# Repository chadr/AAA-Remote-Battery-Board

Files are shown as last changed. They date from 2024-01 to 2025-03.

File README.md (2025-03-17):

# AAA Remote Battery Board - Updated!
 Remote RTC/CMOS/NVRAM battery for retro computer motherboards. Provides about +4.5V. Which is what most vintage motherboards require. +3V, like from a CR2032, is not appropriate!

 **Features:**
 * Higher voltage than CR2032 and higher capacity for longer life
 * Diode to prevent reverse charging
 * Diode delete solder jumper - NEW
 * Universal fuse holder footprint accepts wide and narrow spacing - NEW
 * 100ma fuse to protect motherboard if a short develops
 * Nylon fuse holder contains fuse blast and glass
 * Uses 1x4 pin headers found on most motherboards for simple cabling
 * PCB cutouts for Cable tie to secure batteries in rough service situations
 * Backer board to raise battery off case when using tape/velcro - NEW
 * Mounting holes for M3 standoffs
 * No motherboard modifications required!

<picture>
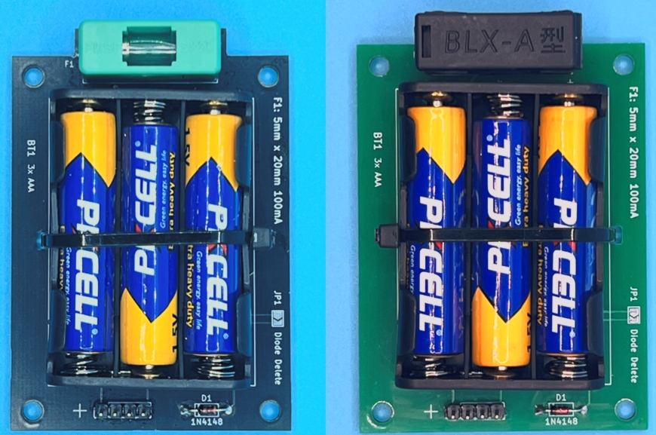
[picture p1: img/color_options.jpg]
AAA Battery Board Assembled
 
</picture>

<picture>
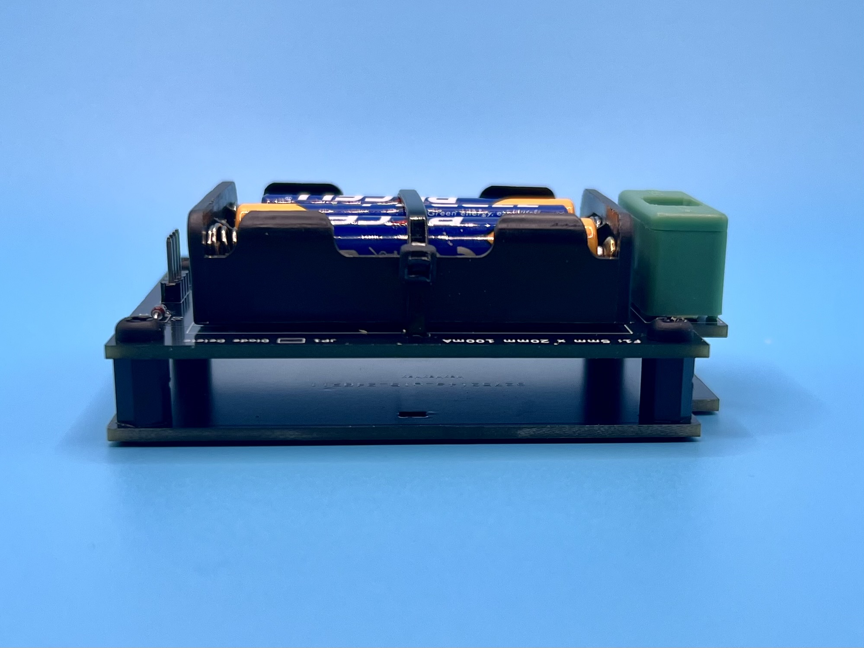
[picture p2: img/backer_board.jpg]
AAA Backer Board
  
</picture>

<picture>
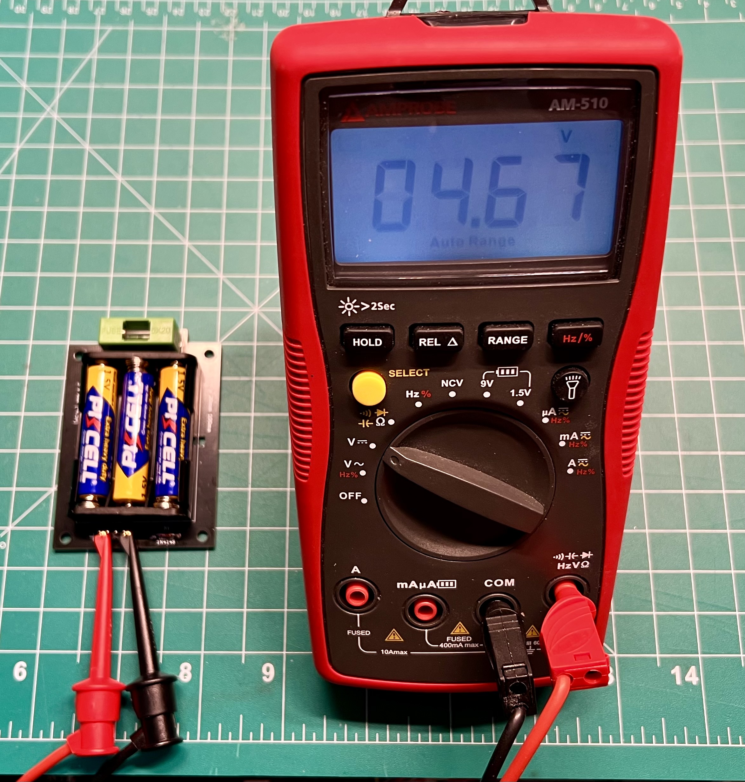
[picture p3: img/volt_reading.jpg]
AAA Battery Board Open Circuit Voltage
 
</picture>

## Here's a scan from a 386sx AT motherboard. Notice the voltages it requires. It warns against using +3V batteries like a CR2032!
<picture>
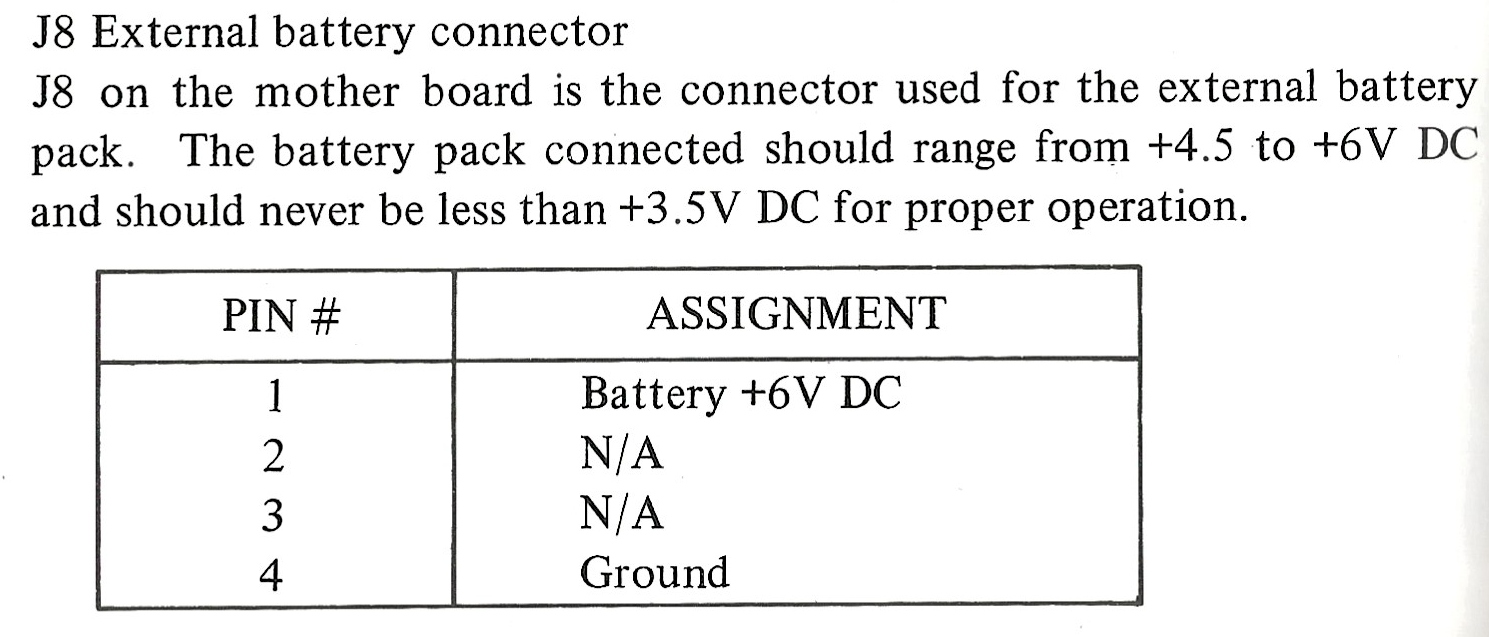
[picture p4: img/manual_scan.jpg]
Manual Scan
  
</picture>

## Bill of Materials
**Item**|**Qty**|**MFG Part Num**|**Mouser Part Num**
:-----:|:-----:|:-----:|:-----:
Keystone 3xAAA Holder|1|2479|534-2479
1N4148 Diode|1|1N4148-T50R|512-1N4148T50R
1x4 2.54mm Male Header|1|826926-4|571-826926-4
Fuse|1|BK1/GMC-100-R|504-BK1-GMC-100-R
Fuse Holder|1|0PTF0078P|576-0PTF0078P
Fuse Clip|1|00BS0232P|576-00BS0232P

## Board Information
Dimensions:  
Layers: 2  
Finish: HASL  
Make sure to choose "custom position" for order number /w JLCPCB or PCBWAY.  

## Purchasing
I sell assembled kits complete with cables, mounting hardware, and batteries in my [eBay store](https://www.ebay.com/str/pcrestoration).  
And on Tindie (Cheaper on Tindie due to lower fees!) [Link](https://www.tindie.com/products/33599/)



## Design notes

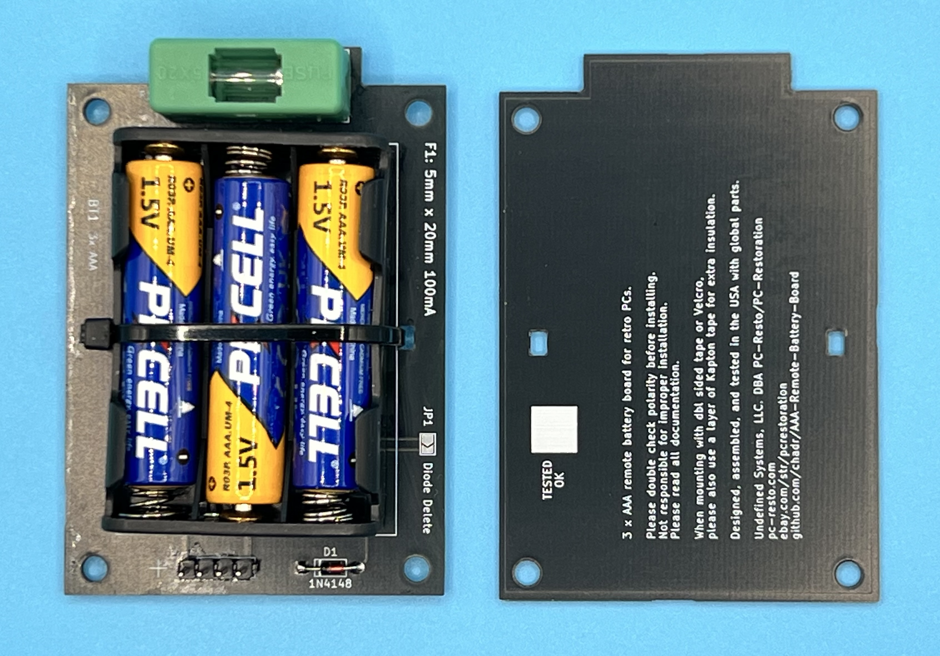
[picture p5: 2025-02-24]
img/with_backer.jpg

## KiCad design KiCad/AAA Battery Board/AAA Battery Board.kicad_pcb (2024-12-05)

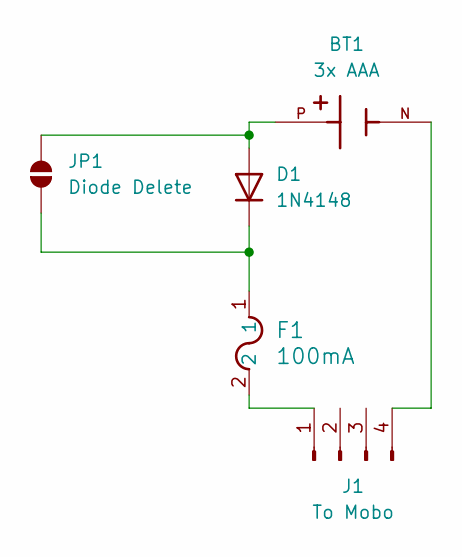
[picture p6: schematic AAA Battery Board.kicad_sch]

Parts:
BT1: 3x AAA; BAT_2479; PARTREV E
D1: 1N4148; D_DO-35_SOD27_P7.62mm_Horizontal
F1: 100mA; UniversalGreenFuseHolder
J1: To Mobo; PinHeader_1x04_P2.54mm_Vertical
JP1: Diode Delete; SolderJumper-2_P1.3mm_Open_TrianglePad1.0x1.5mm

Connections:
unnamed: BT1.P, D1.2 (A), JP1.1 (A)
unnamed: D1.1 (K), F1.1, JP1.2 (B)
unnamed: F1.2, J1.1
unnamed: BT1.N, J1.4

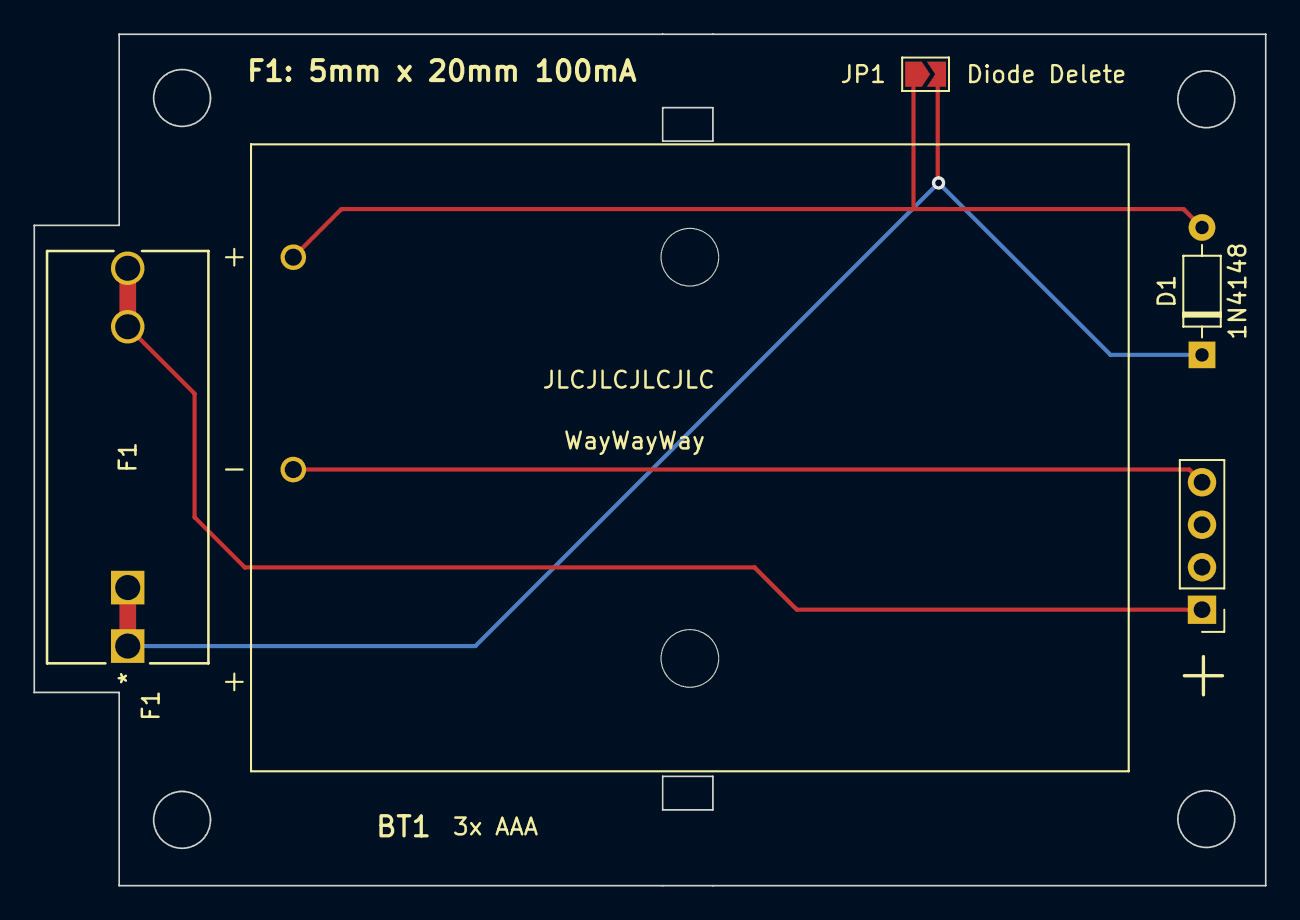
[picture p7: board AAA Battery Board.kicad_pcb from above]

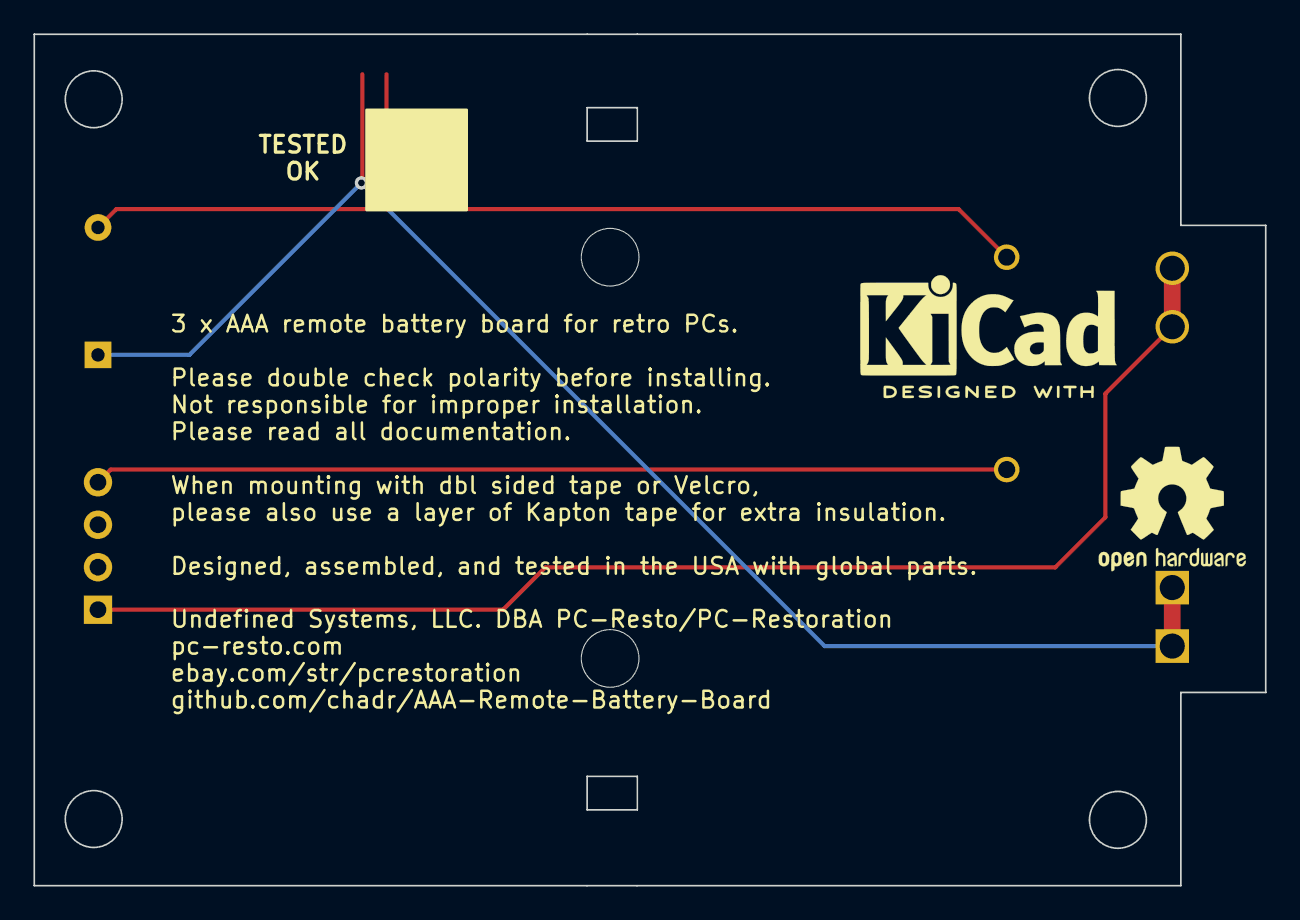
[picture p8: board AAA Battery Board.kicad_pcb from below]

Board: 2 copper layers, 73.7 x 50.9 mm, 7 parts (2 on the bottom side), 4 nets.

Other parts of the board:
KiCad Logo: KiCad-Logo2_6mm_SilkScreen
Open Hardware Logo: OSHW-Logo2_9.8x8mm_SilkScreen

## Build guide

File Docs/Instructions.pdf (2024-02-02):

Note: The solder on the back of the board has clear conformal coating applied for extra insulation. This is not flux residue! Please do not try and clean it off.

Note: A cable tie has been placed around the board to retain batteries during shipping. You can choose to leave this in place or remove it. It's up to you :)

Mounting the Battery Board
I recommend three mounting options (in this order):
1. M3 hardware (included)
2. Velcro
3. Double-sided tape.

When using Velcro or double-sided tape: I STRONGLY recommend you place a layer of Kapton tape on the case metal where you will affix the board. For extra insulation. Then adhere the velcro/double-sided tape to the layer of Kapton. If you don't have Kapton tape, clear packing tape will also work well.

When using double-sided tape: You must use the foam type double-sided tape that has some thickness to it. I STRONGLY recommend you put two layers of foam double-sided tape on top of each other to further raise the board away from the chassis.

Connecting to Motherboard
Only install when certain of correct polarity for your motherboard. Please double and triple check that the polarity is correct before installing. Reverse polarity connections will likely blow the fuse.

Many vintage motherboards with an external battery header will also have a jumper to disable the on-board battery circuit. Please check with your motherboard documentation. If this jumper is present, please set it to the external battery position before connecting this battery board.

Need help finding documentation for your motherboard? Please visit the excellent "The Retro Web" project website: https://theretroweb.com

When all else fails, you can determine the polarity of your motherboard's battery header using a multimeter.
1. Put your meter in cotinuity mode (beeps when you touch the test leads together).
2. Connect one lead to a ground point.
3, Test the left-most and right-most pins of the 4-pin battery header on the motherboard with the other lead. When your meter beeps, it means you have found the ground (negative) pin. The positive pin will be on the opposite side.

AAA Battery Board Kit for Retro and Vintage Computers.

Undefined Systems, LLC dba PC-Resto.

### https://pc-resto.com https://www.ebay.com/str/pcrestoration

Troublehooting

Problem: Fuses keep blowing
This is usueally the result of three potential problems.
1. Cable to motherboard is connected in reverse polarity.
2. Back of battery board is making contact with the metal case of the computer.
3. There is a short in the RTC circuit on your motherboard. Often, this indicates a bad RTC chip.

The fuse used is a standard 5mm x 20mm 100mA fuse. Voltage rating doesn't matter as this is a very low voltage application. These can be readily found on sites like eBay.

Problem: Batteries die quickly
This battery board should last a minimum of 6 months on most computers. Usually it will last for upwards of multiple years.

If the batteries must be changed often, it indicates a problem on the motherboard. A faulty RTC chip can have excessive current draw.

If you have a multimeter with a microamps setting (uA), you can put it in series between the battery board and the motherboard header to measure the current draw. With the computer turned off, the current draw by the RTC chip should be less than 200uA. Even 150uA is a little high and might deserve investigation. But I have seen some Motorola RTC chips pull ~160uA when the computer is off.

## Do not hesitate to contact me if you have any questions! chad@pc-resto.com

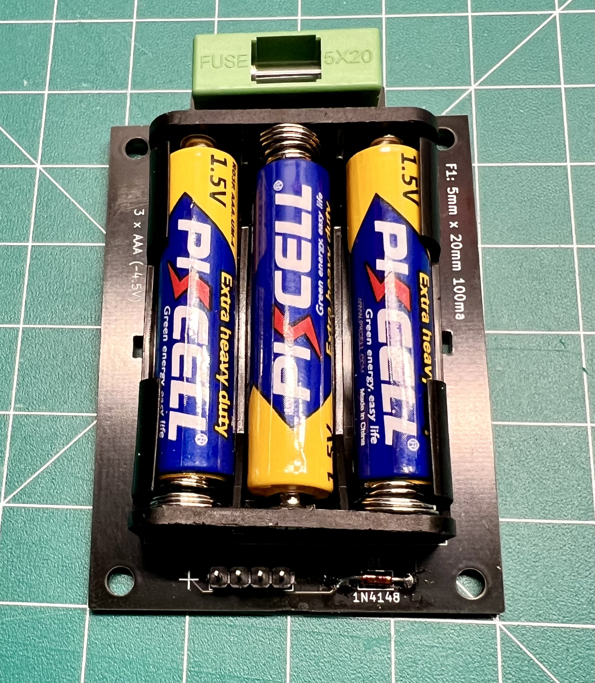
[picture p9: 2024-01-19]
img/assembled.jpg

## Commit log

2023-11-16 update files
    [AAA Battery Board-B_Cu.gbr, AAA Battery Board-B_Mask.gbr, AAA Battery Board-B_Paste.gbr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]
2023-11-27 Add zip tie holes
    [AAA Battery Board-B_Cu.gbr, AAA Battery Board-B_Mask.gbr, AAA Battery Board-B_Paste.gbr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]
2023-12-19 update PCB
    add cutouts for zip ties
    [AAA Battery Board-B_Cu.gbr, AAA Battery Board-B_Mask.gbr, AAA Battery Board-B_Paste.gbr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]
2024-01-20 fix typos
    [AAA Battery Board-B_Cu.gbr, AAA Battery Board-B_Mask.gbr, AAA Battery Board-B_Paste.gbr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]
2024-12-05 Update footprints.
    Update fuse holder footprint to work with both 15mm and 23mm leg spacing versions.
    [AAA Battery Board-B_Cu.gbr, AAA Battery Board-B_Mask.gbr, AAA Battery Board-B_Paste.gbr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]
2025-02-24 update design + files
    [AAA Battery Board-B_Cu.gbr, AAA Battery Board-B_Mask.gbr, AAA Battery Board-B_Paste.gbr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]
